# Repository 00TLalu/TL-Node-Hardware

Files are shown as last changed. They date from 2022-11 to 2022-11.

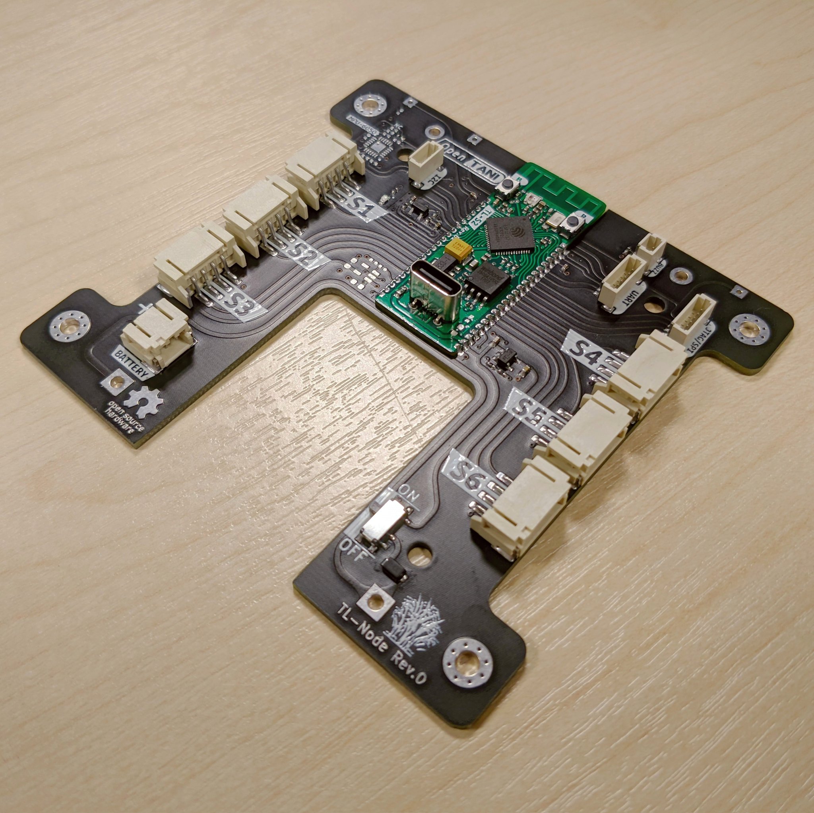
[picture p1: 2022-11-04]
Document/PCB Assemble.jpg

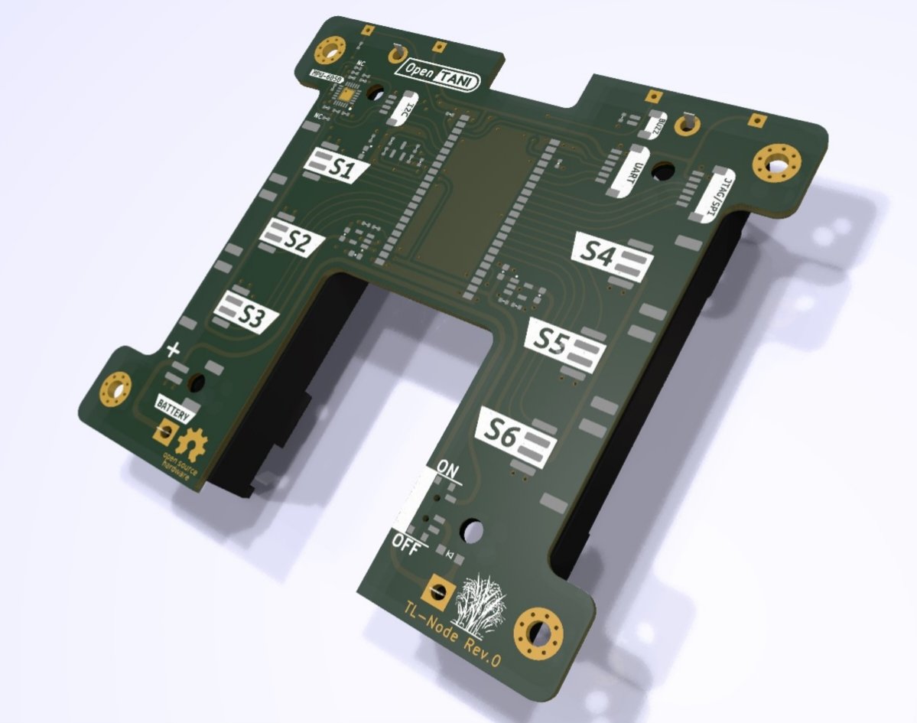
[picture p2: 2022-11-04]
Document/3D Model.jpg

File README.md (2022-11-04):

# TL-Node-Hardware
 PCB for OpenTANI

## Spesification
- TL-S2 (ESP32-S2)
- 2 External LDO
- 6 port 4 pin JST-PH Sensor
- 1 port 2 pin JST-PH Battery
- 1 port 2 pin JST-SH Buzzer
- 1 port 4 pin JST-SH I2C
- 1 port 6 pin JST-SH UART
- 1 port 6 pin JST-SH JTAG/SPI
- 2 Reed Switch
- 2 pcs Battery 18650 Battery
- 1 Programeble LED
- 1 Power Switch
- Voltage/Battery Monitor
- MPU-6050 (Optional)

## Schematic
Schematic TL-Node Rev 0

## 3D Model
3D Model
PCB Dimension

## PCB
PCB Assemble

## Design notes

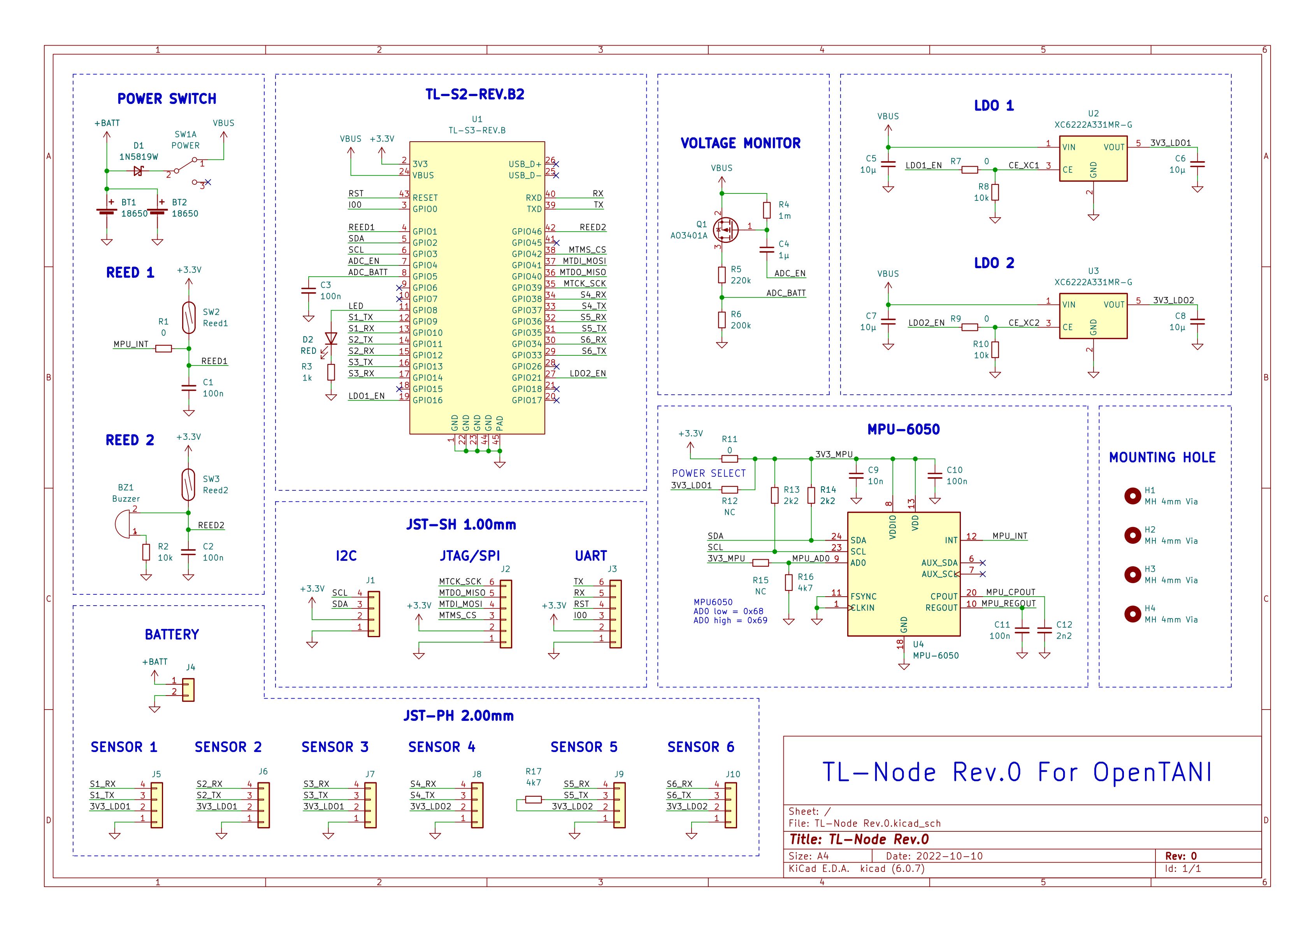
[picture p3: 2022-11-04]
Document/Schematic TL-Node Rev.0.jpeg

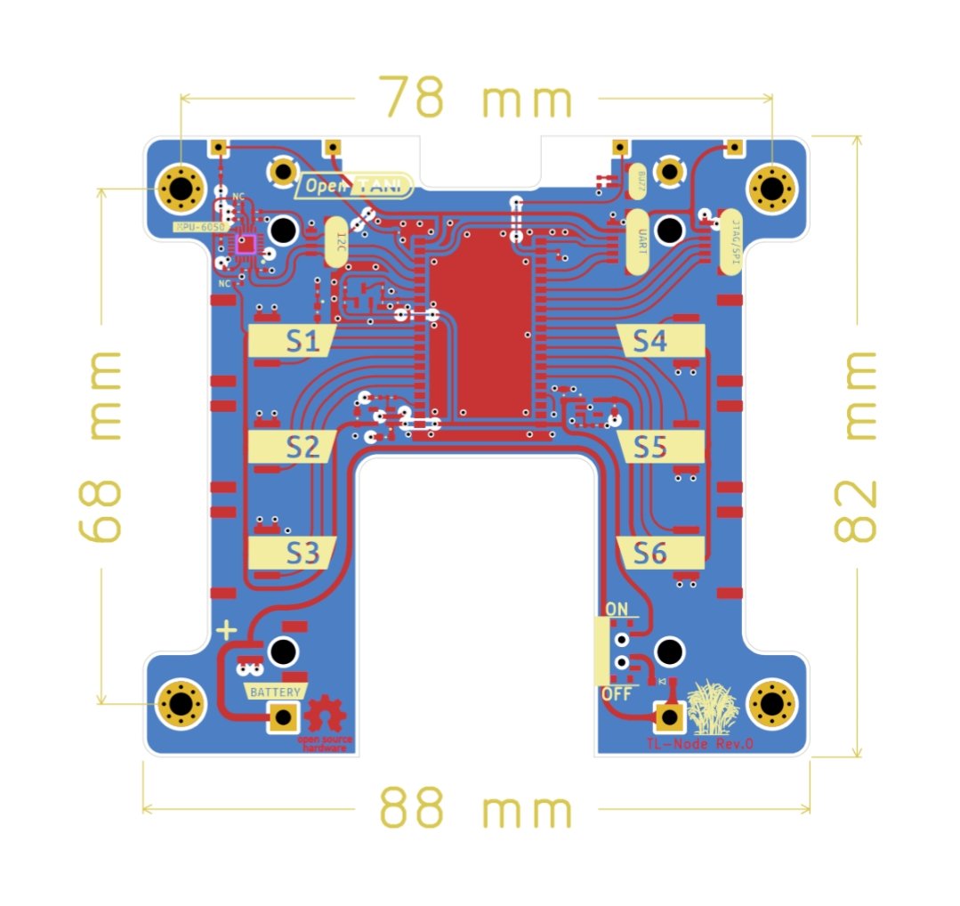
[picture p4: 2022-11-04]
Document/PCB Dimension.jpg

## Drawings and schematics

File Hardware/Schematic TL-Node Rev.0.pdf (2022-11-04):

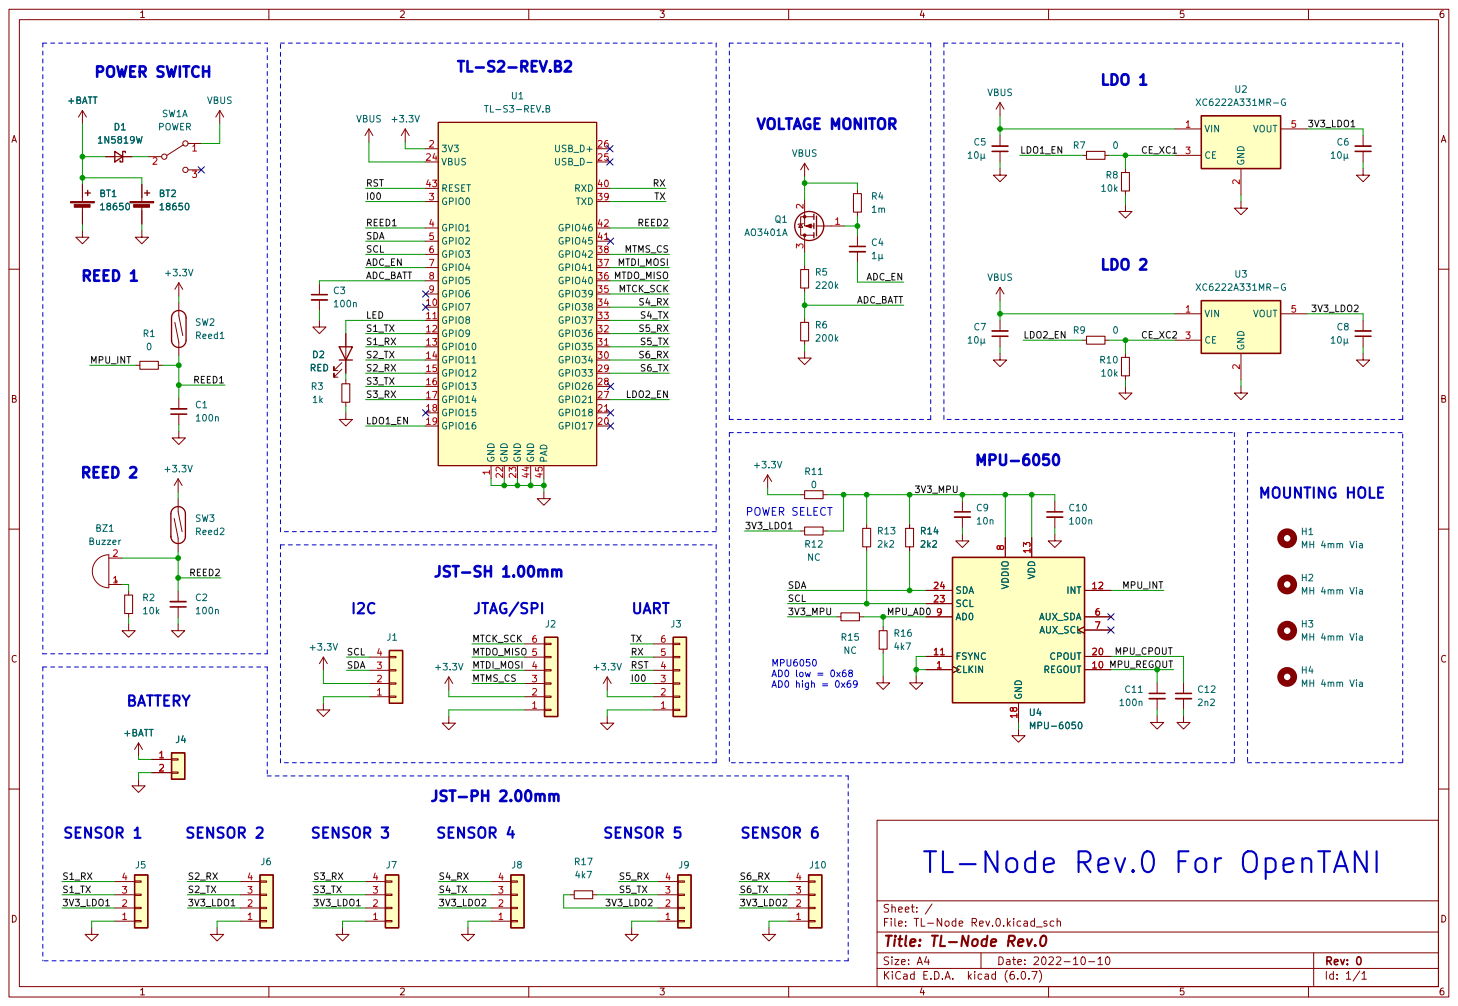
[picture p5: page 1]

Id: 1/1 Title: TL-Node Rev.0

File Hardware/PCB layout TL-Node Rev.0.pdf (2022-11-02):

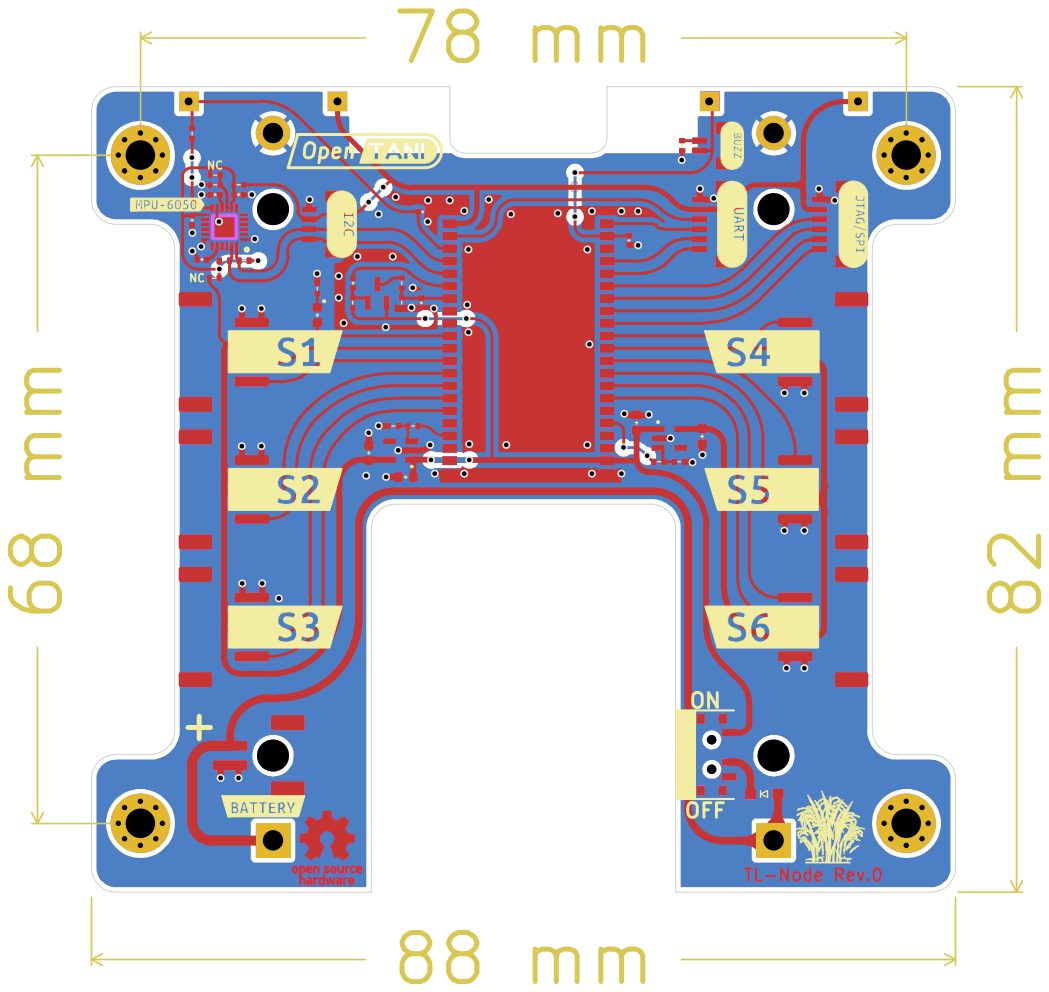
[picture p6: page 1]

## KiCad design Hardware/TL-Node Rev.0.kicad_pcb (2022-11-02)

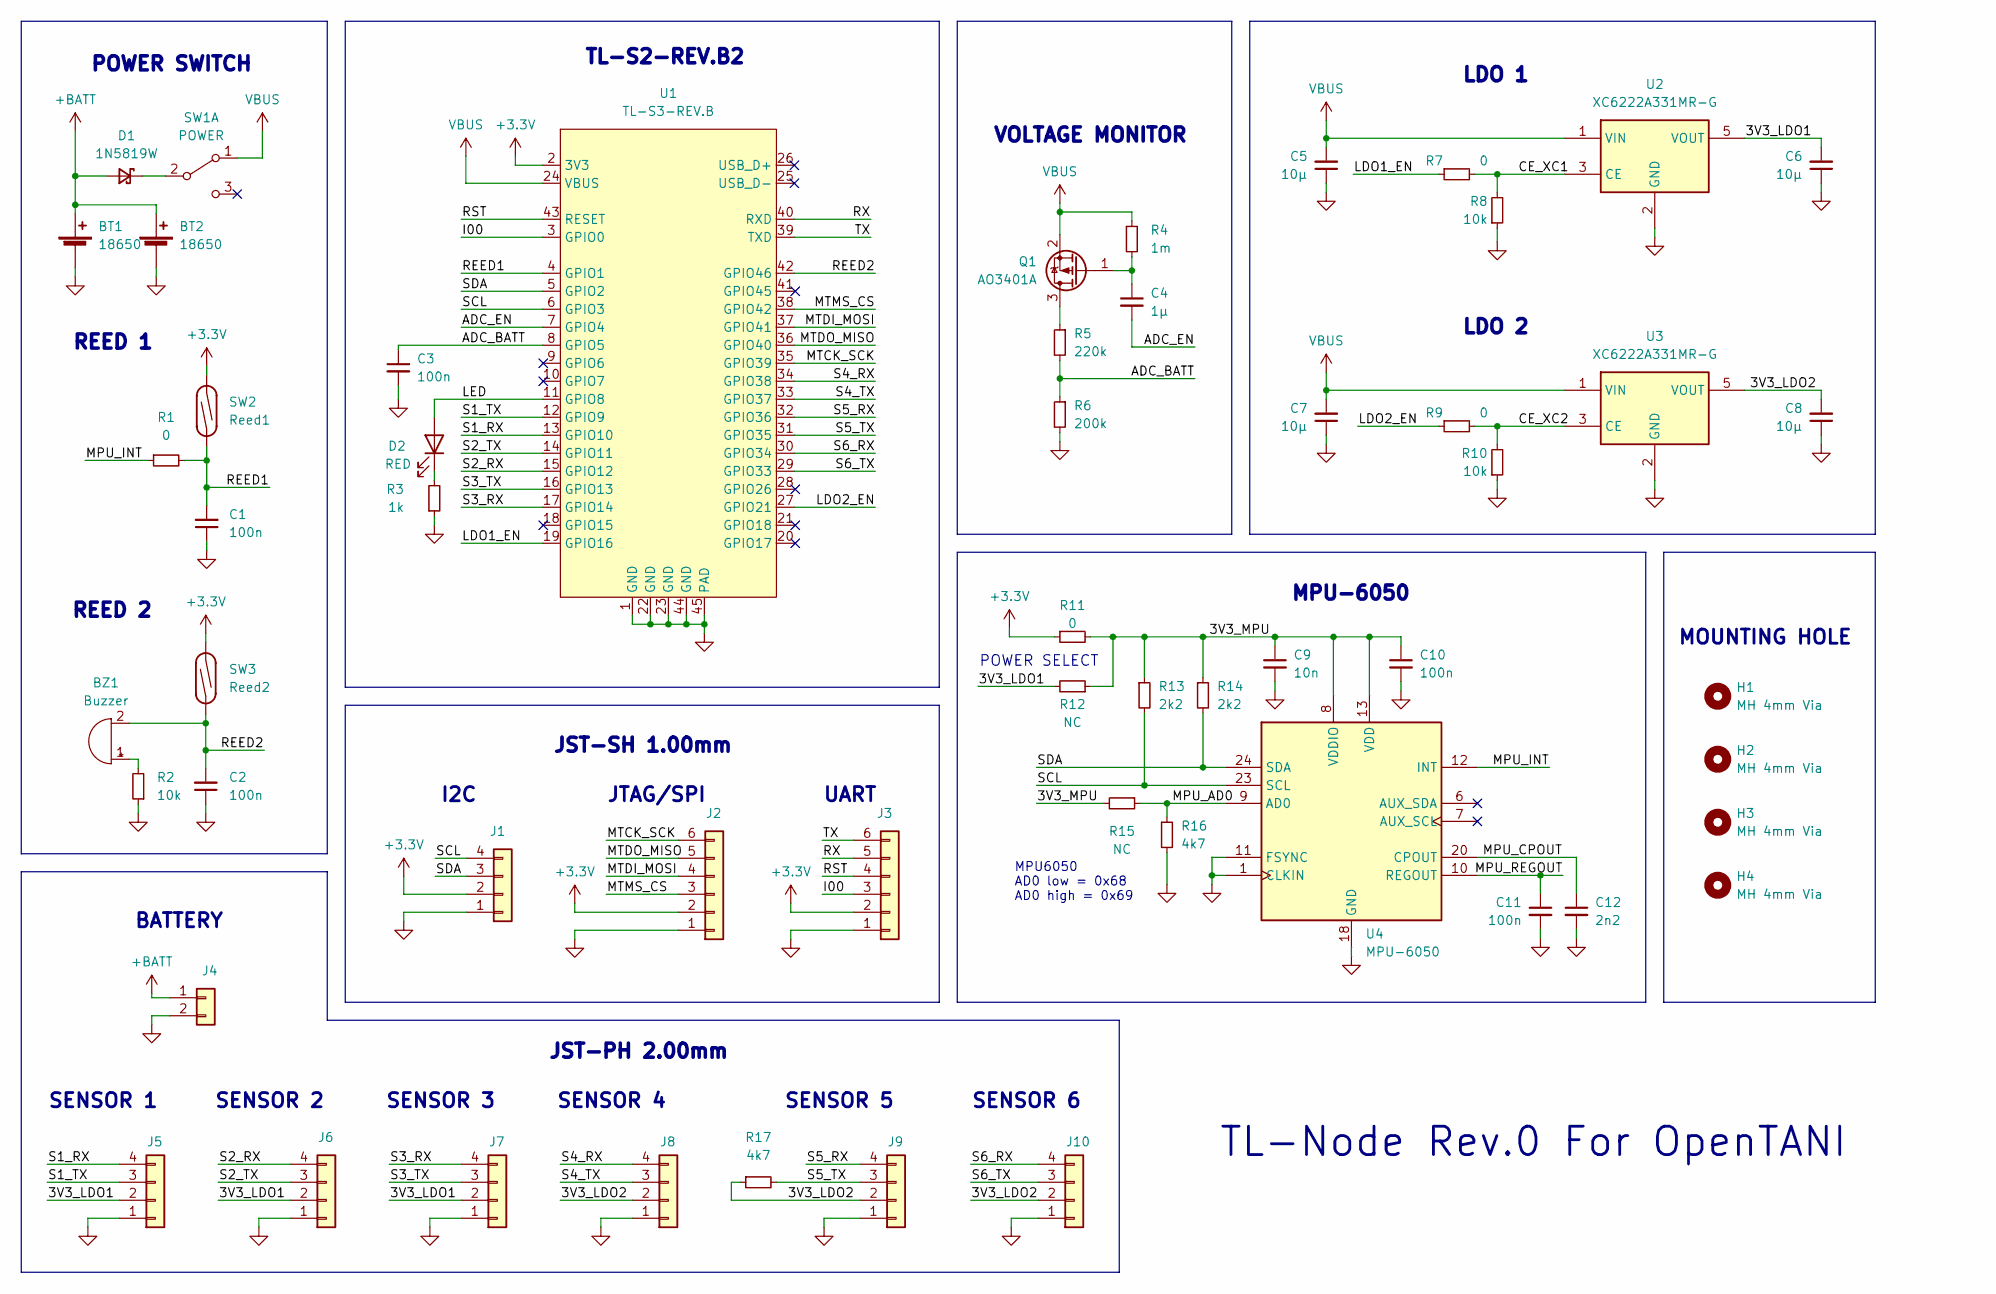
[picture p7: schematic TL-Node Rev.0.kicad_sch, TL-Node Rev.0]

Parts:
BT1, BT2: 18650; BatteryHolder_MPD_BH-18650-PC2
BZ1: Buzzer; JST_SH_BM02B-SRSS-TB_1x02-1MP_P1.00mm_Vertical
C1, C2, C3, C10, C11: 100n; C_0402_TL
C4: 1µ; C_0402_TL
C5, C6, C7, C8: 10µ; C_0603_TL
C9: 10n; C_0402_TL
C12: 2n2; C_0402_TL
D1: 1N5819W; D_SOD-123F
D2: RED; D_0603_TL
H1, H2, H3, H4: MH 4mm Via; MountingHole_3mm_Pad_Via
J1: JST-PH 1x04; JST_SH_BM04B-SRSS-TB_1x04-1MP_P1.00mm_Vertical_TL
J2, J3: JST-SH 1x06; JST_SH_1x06-1MP_P1.00mm_Vertical_TL
J4: JST-PH 1x02; JST_PH_B2B-PH-TL-2.0
J5, J6, J7, J8, J9, J10: JST-PH 1x04; JST_PH_S4B-PH-SM4-TB_1x04-1MP_P2.00mm_Horizontal
Q1: AO3401A; SOT-23_TL
R1, R7, R9, R11: 0; R_0402_TL
R2, R8, R10: 10k; R_0402_TL
R3: 1k; R_0402_TL
R4: 1m; R_0402_TL
R5: 220k; R_0402_TL
R6: 200k; R_0402_TL
R12, R15: NC; R_0402_TL
R13, R14: 2k2; R_0402_TL
R16, R17: 4k7; R_0402_TL
SW1: POWER; SW_SPDT_PCM12_TL
SW2: Reed1; SW_SPST_REED_CT10-XXXX-G1
SW3: Reed2; SW_SPST_REED_CT10-XXXX-G1
U1: TL-S3-REV.B; TL-S2_Rev.B2
U2, U3: XC6222A331MR-G; SOT-23-5_TL
U4: MPU-6050; InvenSense_QFN-24_4x4mm_P0.5mm_NoMask

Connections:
+3.3V: J1.2, J2.2, J3.2, R11.1, SW2.1, SW3.1, U1.2 (3V3)
+BATT: BT1.1 (+), BT2.1 (+), D1.2 (A), J4.1
/3V3_LDO1: C6.2, J5.2, J6.2, J7.2, R12.2, U2.5 (VOUT)
/3V3_LDO2: C8.2, J8.2, J9.2, J10.2, R17.1, U3.5 (VOUT)
/3V3_MPU: C9.1, C10.1, R11.2, R12.1, R13.1, R14.1, R15.2, U4.8 (VDDIO), U4.13 (VDD)
/ADC_BATT: C3.1, R5.2, R6.1, U1.8 (GPIO5)
/ADC_EN: C4.2, U1.7 (GPIO4)
/I00: J3.3, U1.3 (GPIO0)
/LDO1_EN: R7.1, U1.19 (GPIO16)
/LDO2_EN: R9.1, U1.27 (GPIO21)
/LED: D2.2 (A), U1.11 (GPIO8)
/MPU_AD0: R15.1, R16.1, U4.9 (AD0)
/MPU_CPOUT: C12.1, U4.20 (CPOUT)
/MPU_INT: R1.1, U4.12 (INT)
/MPU_REGOUT: C11.1, U4.10 (REGOUT)
/MTCK_SCK: J2.6, U1.35 (GPIO39)
/MTDI_MOSI: J2.4, U1.37 (GPIO41)
/MTDO_MISO: J2.5, U1.36 (GPIO40)
/MTMS_CS: J2.3, U1.38 (GPIO42)
/REED1: C1.2, R1.2, SW2.2, U1.4 (GPIO1)
/REED2: BZ1.2 (+), C2.2, SW3.2, U1.42 (GPIO46)
/RST: J3.4, U1.43 (RESET)
/RX: J3.5, U1.40 (RXD)
/S1_RX: J5.4, U1.13 (GPIO10)
/S1_TX: J5.3, U1.12 (GPIO9)
/S2_RX: J6.4, U1.15 (GPIO12)
/S2_TX: J6.3, U1.14 (GPIO11)
/S3_RX: J7.4, U1.17 (GPIO14)
/S3_TX: J7.3, U1.16 (GPIO13)
/S4_RX: J8.4, U1.34 (GPIO38)
/S4_TX: J8.3, U1.33 (GPIO37)
/S5_RX: J9.4, U1.32 (GPIO36)
/S5_TX: J9.3, R17.2, U1.31 (GPIO35)
/S6_RX: J10.4, U1.30 (GPIO34)
/S6_TX: J10.3, U1.29 (GPIO33)
/SCL: J1.4, R13.2, U1.6 (GPIO3), U4.23 (SCL)
/SDA: J1.3, R14.2, U1.5 (GPIO2), U4.24 (SDA)
/TX: J3.6, U1.39 (TXD)
GND: BT1.2 (-), BT2.2 (-), C1.1, C2.1, C3.2, C5.1, C6.1, C7.1, C8.1, C9.2, C10.2, C11.2, C12.2, J1.1, J2.1, J3.1, J4.2, J5.1, J6.1, J7.1, J8.1, J9.1, J10.1, R2.1, R3.1, R6.2, R8.1, R10.1, R16.2, U1.1 (GND), U1.22 (GND), U1.23 (GND), U1.44 (GND), U1.45 (PAD), U2.2 (GND), U3.2 (GND), U4.1 (CLKIN), U4.11 (FSYNC), U4.18 (GND)
unnamed: BZ1.1 (-), R2.2
unnamed: C4.1, Q1.1 (G), R4.2
unnamed: D1.1 (K), SW1.2 (B)
unnamed: D2.1 (K), R3.2
unnamed: Q1.3 (D), R5.1
unnamed: R7.2, R8.2, U2.3 (CE)
unnamed: R9.2, R10.2, U3.3 (CE)
VBUS: C5.2, C7.2, Q1.2 (S), R4.1, SW1.1 (A), U1.24 (VBUS), U2.1 (VIN), U3.1 (VIN)

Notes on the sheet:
LDO 2
TL-S2-REV.B2
SENSOR 4
TL-Node Rev.0 For OpenTANI
SENSOR 5
SENSOR 6
MPU-6050
VOLTAGE MONITOR
REED 1
JTAG/SPI
MOUNTING HOLE
SENSOR 3
MPU6050 AD0 low = 0x68 AD0 high = 0x69
UART
REED 2
BATTERY
POWER SWITCH
JST-PH 2.00mm
JST-SH 1.00mm
SENSOR 1
I2C
POWER SELECT
LDO 1
SENSOR 2

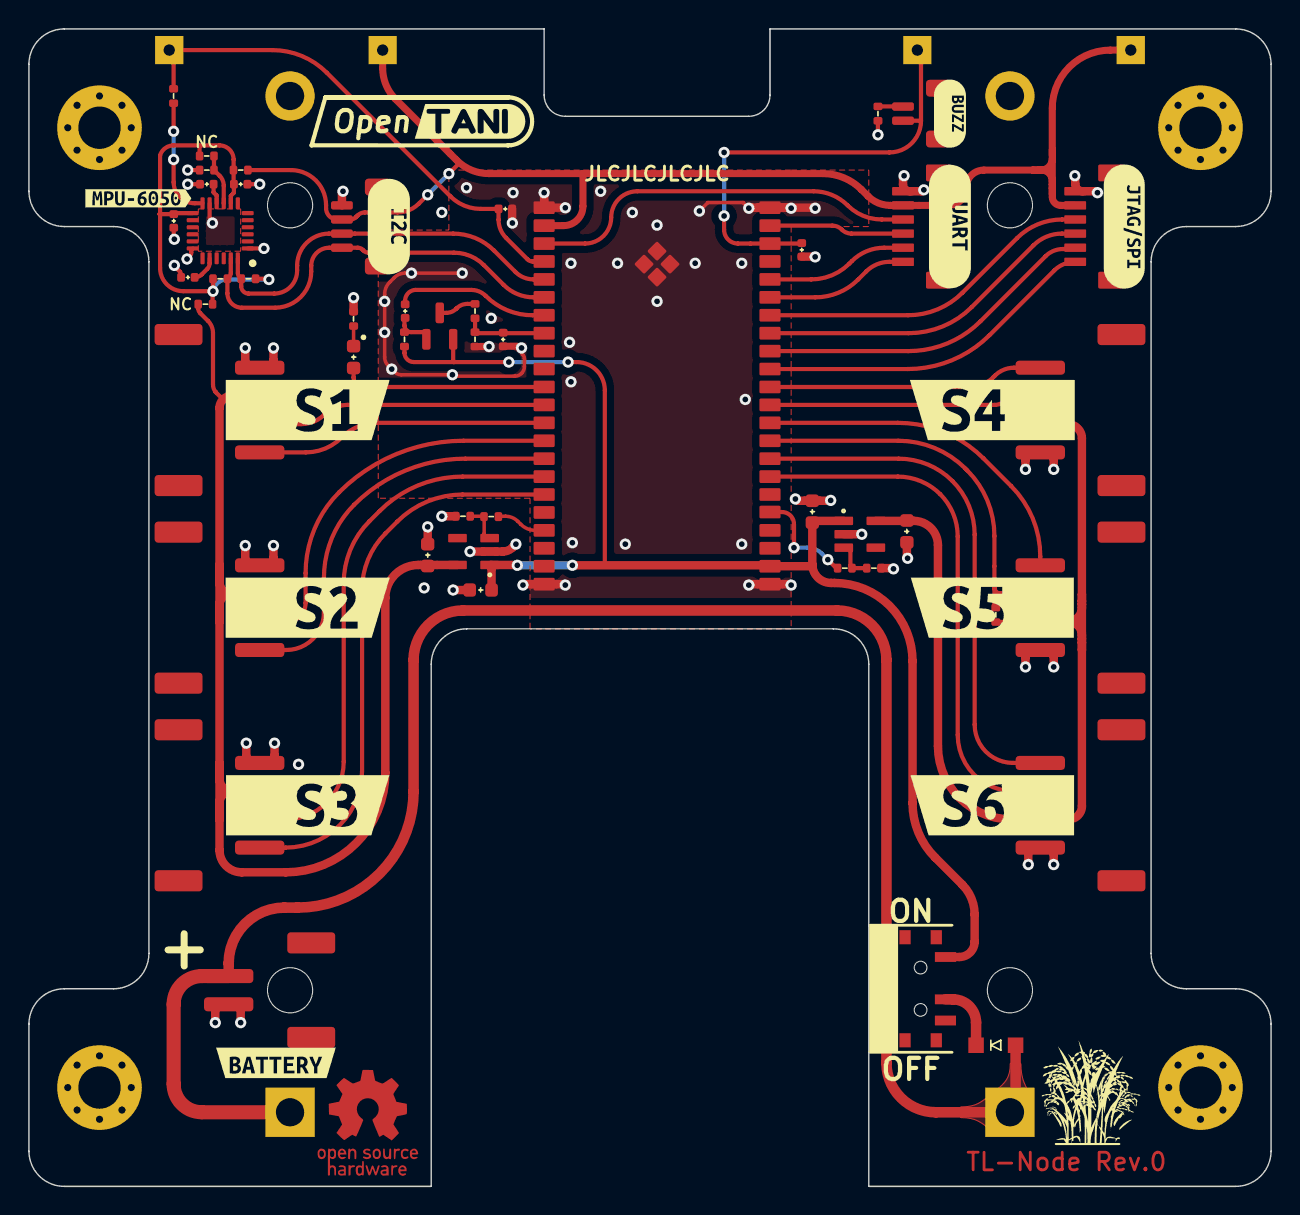
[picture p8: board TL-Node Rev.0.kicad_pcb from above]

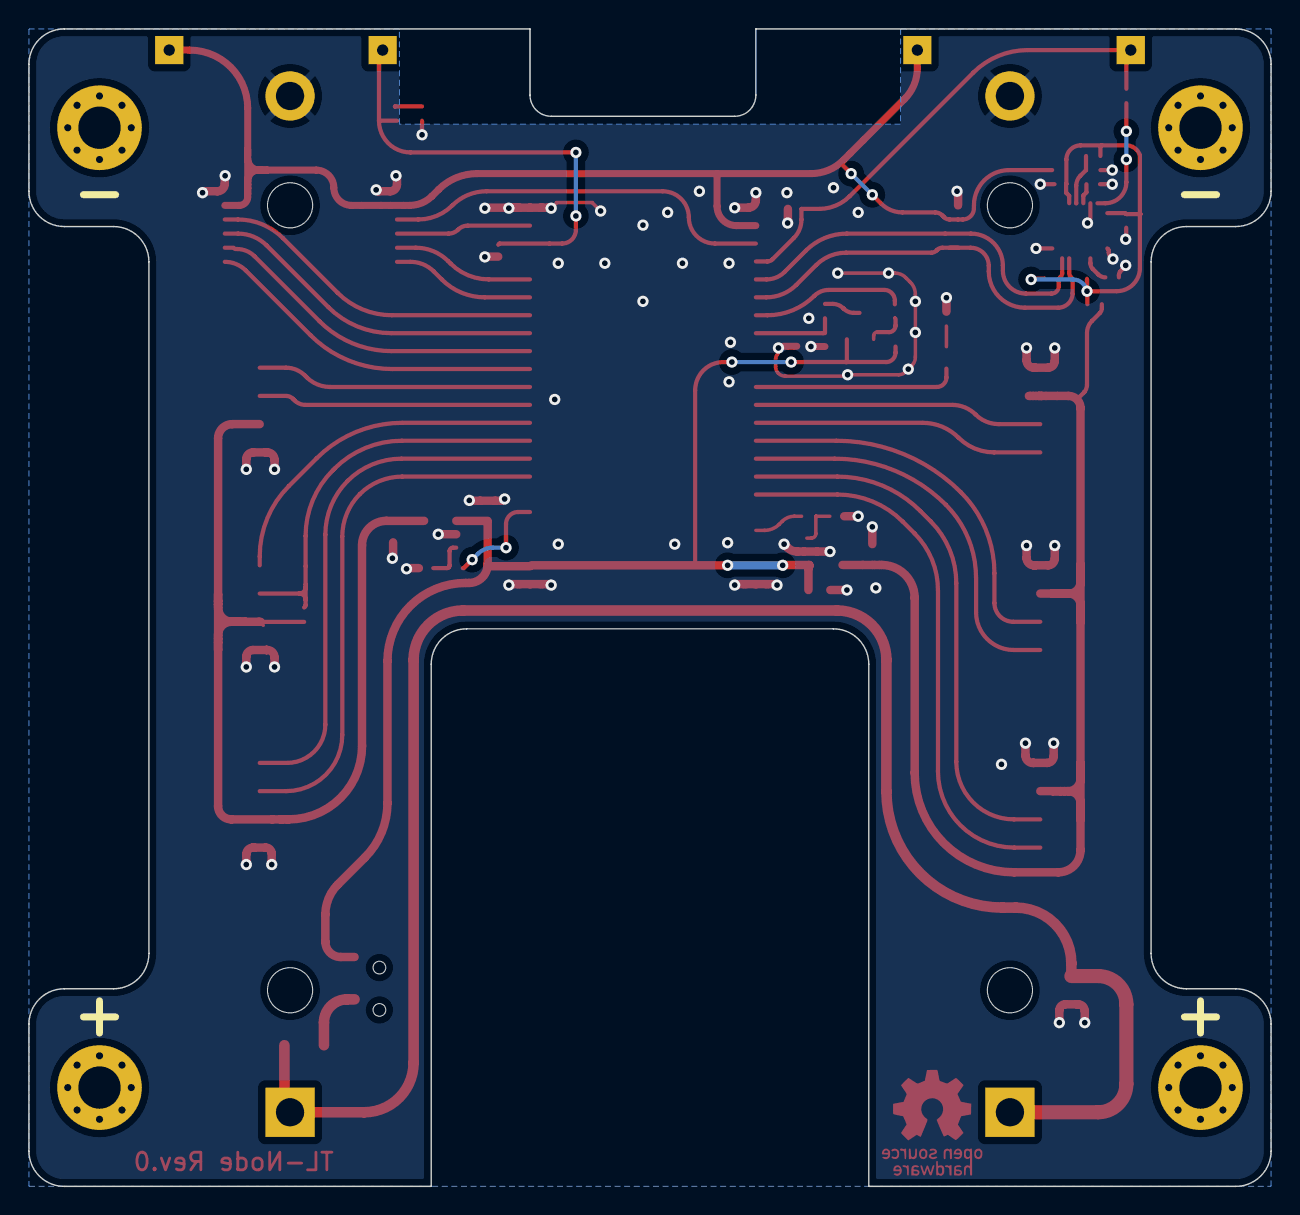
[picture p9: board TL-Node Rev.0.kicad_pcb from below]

Board: 2 copper layers, 88.0 x 82.0 mm, 69 parts (2 on the bottom side), 47 nets.

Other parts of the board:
kibuzzard-6343A6AD: G***; kibuzzard-6343A6AD
kibuzzard-6343A6B9: G***; kibuzzard-6343A6B9
kibuzzard-6343A87B: G***; kibuzzard-6343A87B
kibuzzard-6343A88C: G***; kibuzzard-6343A88C
kibuzzard-6343A679: G***; kibuzzard-6343A679
kibuzzard-6343A848: G***; kibuzzard-6343A848
kibuzzard-6343B0FA: G***; kibuzzard-6343B0FA
kibuzzard-6343B22B: G***; kibuzzard-6343B22B
kibuzzard-6343B029: G***; kibuzzard-6343B029
kibuzzard-6343BC66: G***; kibuzzard-6343BC66
kibuzzard-634399EB: G***; kibuzzard-634399EB
kibuzzard-634411D5: G***; kibuzzard-634411D5
kibuzzard-63441851: G***; kibuzzard-63441851

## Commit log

2022-11-02 add hardware
    [TL-Node Rev.0-B_Cu.gbr, TL-Node Rev.0-B_Mask.gbr, TL-Node Rev.0-B_Paste.gbr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]
2022-11-04 Create Schematic TL-Node Rev.0.jpeg
